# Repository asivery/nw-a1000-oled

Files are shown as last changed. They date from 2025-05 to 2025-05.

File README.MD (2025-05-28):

# A replacement display for the NW-A1000 Network Walkman

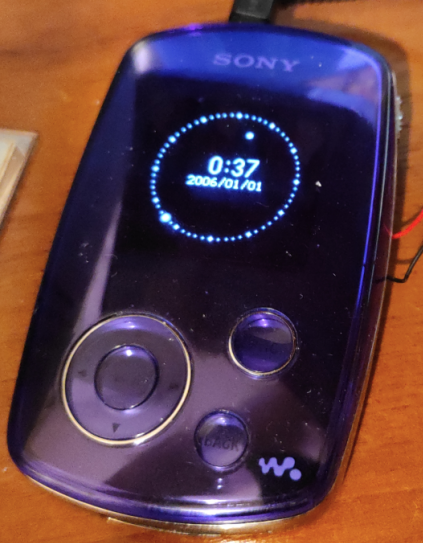
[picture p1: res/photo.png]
Photo of a device with a working screen.


## How it works

Since the Sony NW-A1000 uses an obsolete SSD1328U1-based screen, to make it work with a generic SSD1327 screen I had to patch the firmware.

There's, of course, no new screens available with that exact pinout, so I designed a flex PCB which simply translates the pin layout to the one used by new OLEDs.

[Here](https://aliexpress.com/item/1005006480988390.html)'s the screen I used.

## How to patch?

1. Download the official Sony upgrade tool for the NW-A1000, and start it with the walkman unplugged.
2. Once you see this window, open task manager.

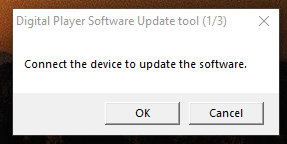
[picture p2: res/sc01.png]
Connect the device to update the software.


3. Open task manager, find `FWUpdater.exe`, right click, select `Open file location`. Then copy all the files to somewhere on your desktop.

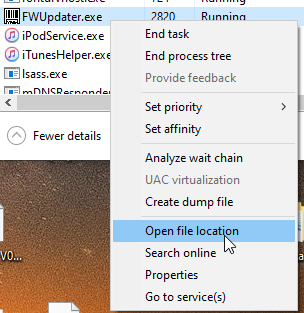
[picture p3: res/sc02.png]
Open file location


4. Go to [my patching site](https://asivery.github.io/NW-A1000/), and provide it the `ver3.00/NW_A1000.UPG` file from that folder.
5. Download the new file, delete all files in `ver3.00` and replace them with the one from my site.
6. Run the patcher and flash the Walkman.

## Is the NW-A1200 / NW-A3000 supported?

I don't know - I haven't tested them with this method, but probably.

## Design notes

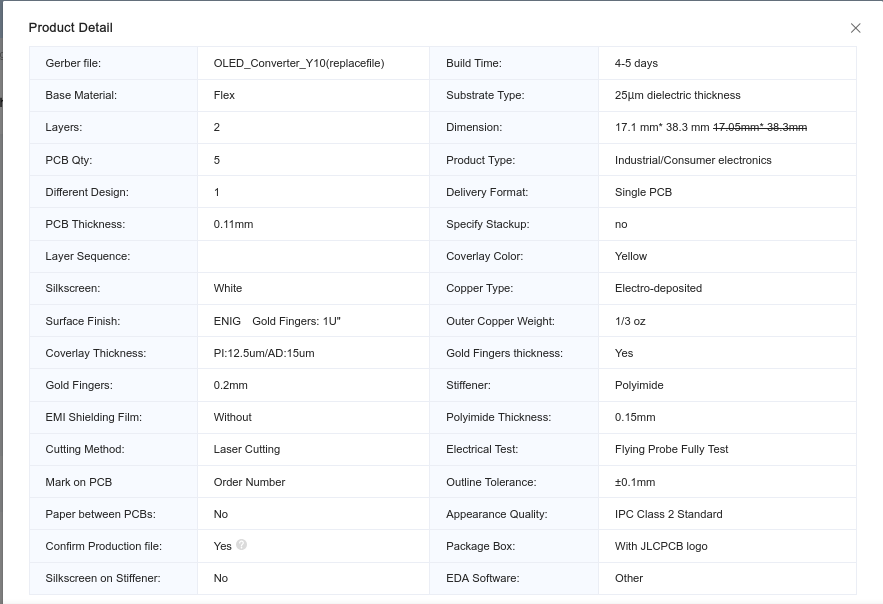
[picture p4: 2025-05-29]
Hardware/production/jlc-config.png

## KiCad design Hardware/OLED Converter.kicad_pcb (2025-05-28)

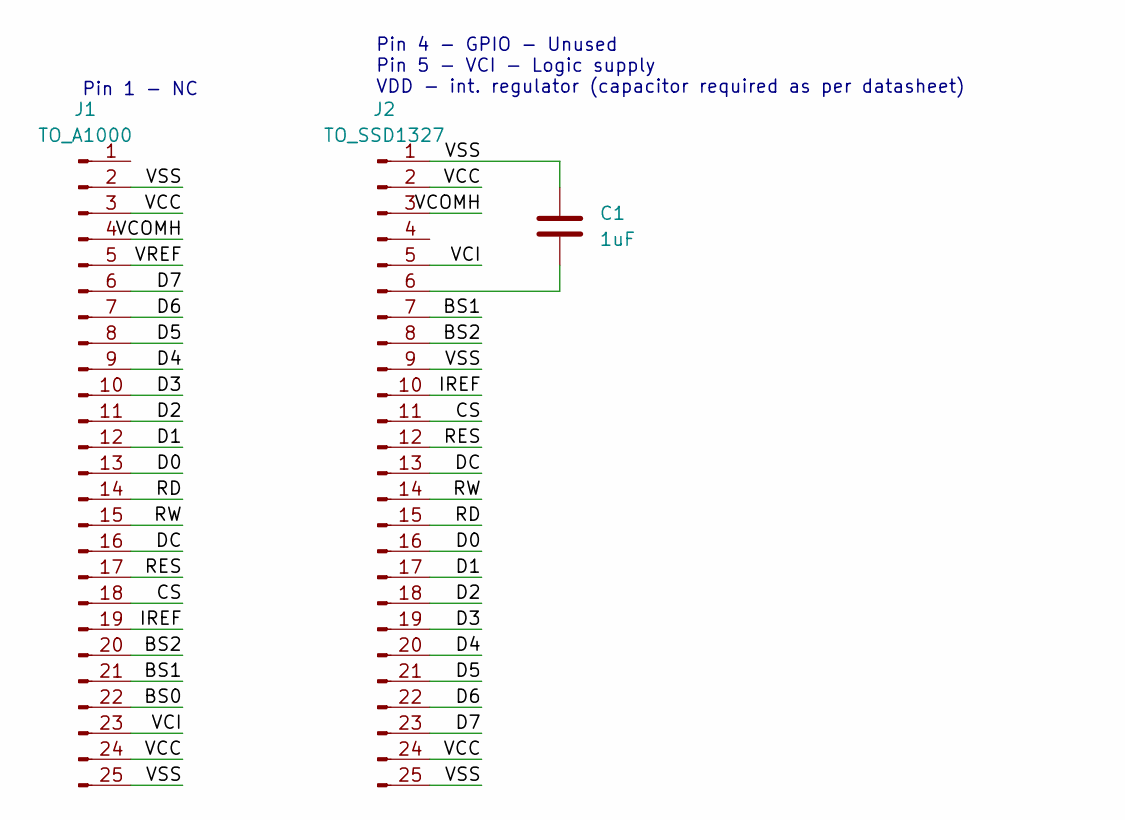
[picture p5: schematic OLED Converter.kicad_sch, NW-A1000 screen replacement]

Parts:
C1: 1uF; C_0402_1005Metric_Pad0.74x0.62mm_HandSolder
J1: TO_A1000; FFC25_0.3
J2: TO_SSD1327; SSD1327_ribbon

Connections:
/BS0: J1.22
/BS1: J1.21, J2.7
/BS2: J1.20, J2.8
/CS: J1.18, J2.11
/D0: J1.13, J2.16
/D1: J1.12, J2.17
/D2: J1.11, J2.18
/D3: J1.10, J2.19
/D4: J1.9, J2.20
/D5: J1.8, J2.21
/D6: J1.7, J2.22
/D7: J1.6, J2.23
/DC: J1.16, J2.13
/IREF: J1.19, J2.10
/RD: J1.14, J2.15
/RES: J1.17, J2.12
/RW: J1.15, J2.14
/VCC: J1.3, J1.24, J2.2, J2.24
/VCI: J1.23, J2.5
/VCOMH: J1.4, J2.3
/VREF: J1.5
/VSS: C1.1, J1.2, J1.25, J2.1, J2.9, J2.25
unnamed: C1.2, J2.6

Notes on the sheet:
Pin 4 - GPIO - Unused Pin 5 - VCI - Logic supply VDD - int. regulator (capacitor required as per datasheet)
Pin 1 - NC

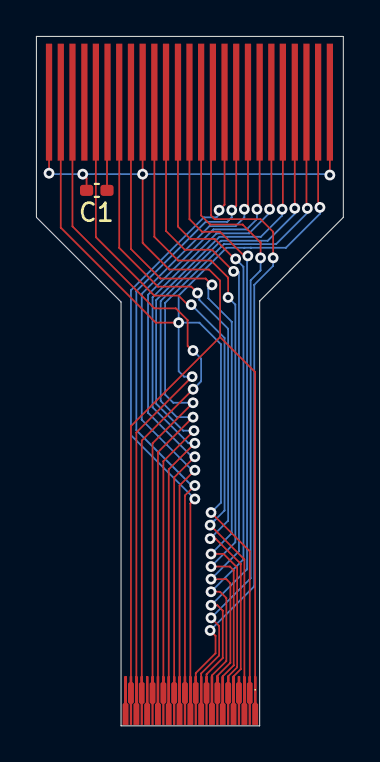
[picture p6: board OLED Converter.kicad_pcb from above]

Board: 2 copper layers, 17.1 x 38.3 mm, 3 parts (0 on the bottom side), 21 nets.
